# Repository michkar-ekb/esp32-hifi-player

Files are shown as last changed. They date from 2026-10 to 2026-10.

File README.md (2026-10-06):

# S3 Hi-Fi

**English** · [Русский](README.ru.md)

A network Hi-Fi player for your own music library (FLAC, WAV, MP3, DSD) and internet radio. The music lives on a home server;
the player, built on an ESP32-S3, receives a ready-to-play stream over Wi-Fi and feeds it
to an ES9038Q2M DAC. You control it from your phone, in the browser.

> **Status:** in daily use at home. Server 0.5, player firmware 0.6, case and wiring are done.
> No display on purpose: everything is on the phone, cover art included. Next: more connections
> for listening over mobile internet (in a car), and a Windows installer.

<p>
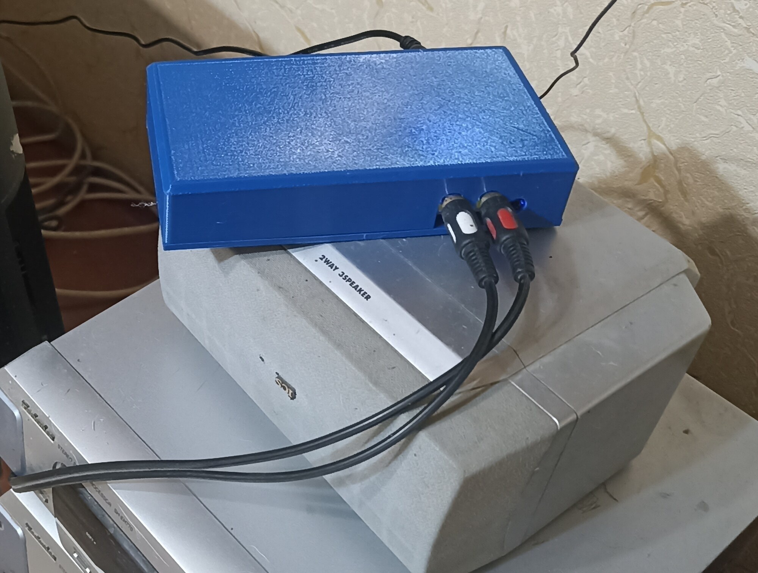
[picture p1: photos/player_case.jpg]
Player in its case on the stereo
  
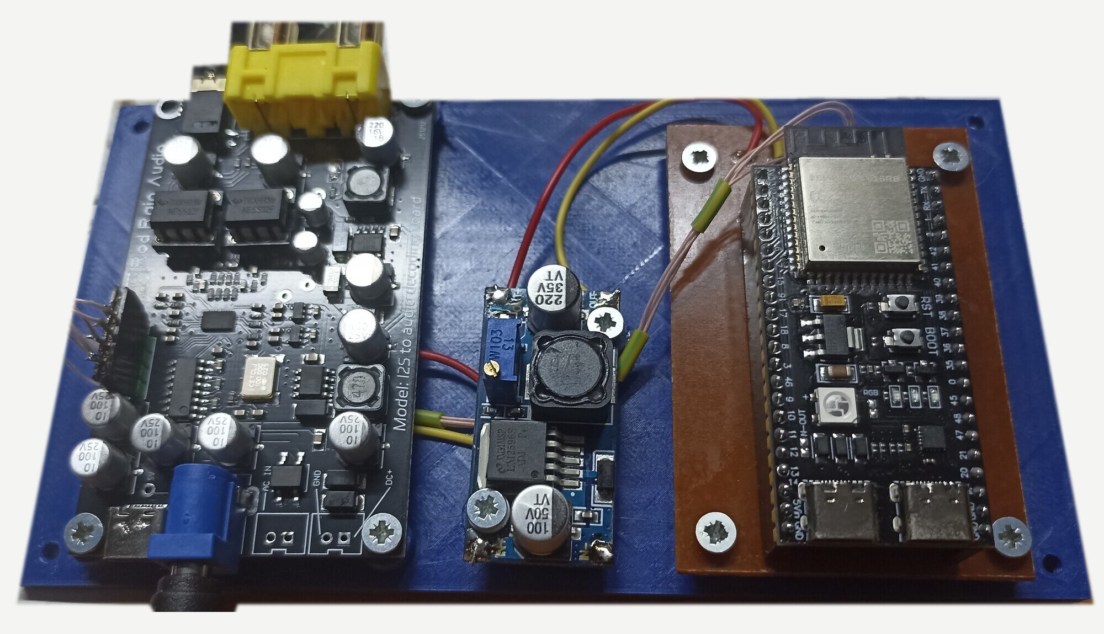
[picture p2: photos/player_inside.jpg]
Inside: DAC, DC-DC module and the ESP32-S3 terminal board
  
</p>

The bench build: in the case on the stereo, and inside.

Block diagram

## Quick start

1. **Server** on a Linux PC that holds the music:
   `curl -fsSL https://raw.githubusercontent.com/michkar-ekb/esp32-hifi-player/main/install.sh | sudo sh -s -- /path/to/music`
   (Windows: [`s3hifi-windows-amd64.exe`](https://github.com/michkar-ekb/esp32-hifi-player/releases/latest), see [server](server)).
2. **Player**: flash `s3hifi-player-esp32s3-n16r8.bin` from [Releases](https://github.com/michkar-ekb/esp32-hifi-player/releases/latest),
   connect a phone to the "S3 Hi-Fi Setup" Wi-Fi and pick your network. The player finds the server by itself.
3. **Remote**: open `http://<server>:8097` on the phone.

## How it works

- **Streaming server** (a home PC or a mini PC, Windows or Linux) stores the music, decodes
  FLAC / WAV / MP3 / DSD and MP3 radio to PCM, keeps the play queue and the radio list,
  and serves the web remote.
- **ESP32-S3** decodes nothing: it receives the PCM stream over TCP, keeps a ~10 second
  buffer in PSRAM and plays it out over I2S at a steady rate. The player sets the pace,
  so the server clock and the player clock never drift apart.
- **ES9038Q2M DAC** has its own oscillator (no MCLK needed) and drives a ~2 V line output
  into an amplifier or powered speakers.

Quality ceiling is 24-bit / 96 kHz: the stream is 4.6 Mbit/s, well within what Wi-Fi delivers.

## Parts

| Block | Part | Notes |
|---|---|---|
| Player | ESP32-S3 DevKitC-1, **N16R8** | PSRAM is required for the buffer |
| DAC | ES9038Q2M board (Rod Rain Audio) | I2S input: GND, BCLK, FSCLK, DATA; RCA output |
| Power | 12 V / 2 A adapter + DC-DC step-down module 12 → 5 V | 12 V goes to the DAC, 5 V to the ESP32-S3 |
| Terminal board | ESP32-S3 terminal board (in this repository) | sockets for the devkit + 6 pads for wires |

## Wiring

Wiring diagram

| ESP32-S3 | Terminal board pad | DAC |
|---|---|---|
| 5V | 5V | — (from the DC-DC module) |
| GND | GND | — (from the DC-DC module) |
| GPIO42 | DATA | DATA |
| GPIO2 | LRCK | FSCLK |
| GPIO1 | BCLK | BCLK |
| GND | GND_A | GND |

Power is split as a **star right at the DAC input jack**: one pair of wires goes to the DAC,
the other to the DC-DC module. The ESP32 current never flows through the DAC's traces.

## ESP32-S3 terminal board

The devkit plugs into sockets, and every signal the player needs comes out to large pads
for soldering wires. Single-sided, 48 × 69.65 mm, all traces on the bottom layer, made for toner transfer
or a marker on a 3D printer.

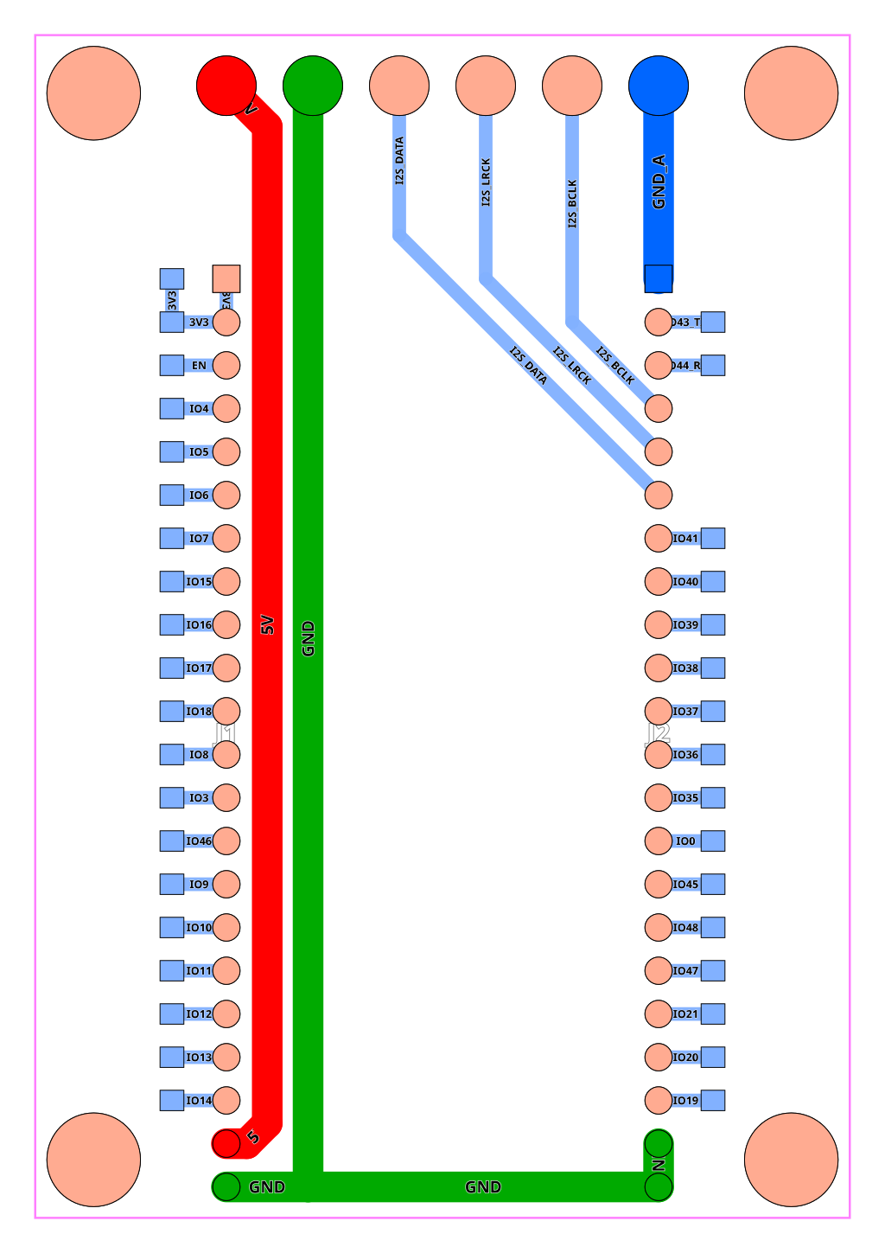
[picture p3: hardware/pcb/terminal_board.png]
Terminal board layout


- `hardware/pcb/terminal_board_gerber.zip` — Gerber files to order or etch the board
- `hardware/pcb/terminal_board_bottom_marker.stl` — bottom layer for marker plotting (mirrored, 0.2 mm)

## Software

- [`server/`](server) — streaming server in Go with the built-in web remote: folders, queue, radio.
  One binary for **Windows and Linux**.
- [`firmware/`](firmware) — player firmware for the ESP32-S3 (Arduino core 2.0.17).

The ES9038Q2M board needs **32-bit I2S samples**; with 16-bit slots it plays noise.
DSD is converted to PCM 24 bit / 88.2 kHz on the server: the board's I2S header cannot carry native DSD.

## Case

3D-printed base plate and lid, `hardware/case/`: the DAC, the DC-DC module and the terminal board
on standoffs; RCA and the headphone jack at the front, 12 V and both USB-C at the rear.
Rounded 3 mm edges, printed without supports. Four M3 × 12 screws hold the lid from below.
This is just one way to house it: any case that fits your modules will do.

## License

Code: MIT. Schematic and board: CC BY-SA 4.0 — build it, change it, just credit the author.

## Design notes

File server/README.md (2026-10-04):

# Streaming server

A single program written in Go. It keeps the music library and the play queue, decodes
everything to PCM and streams it to the player. The web remote for the phone is built in.

- **Formats:** FLAC, WAV (16/24 bit), MP3, DSD (DSF / DFF, DSD64–DSD256) and MP3 internet radio
  are decoded by the server itself.
- **With ffmpeg installed** (optional; next to the server or in PATH) it also plays M4A / ALAC, AAC,
  OGG, Opus, APE, WavPack, AIFF and WMA, and "DTS-WAV" discs: a WAV that actually holds a DTS 5.1
  stream. The server spots DTS / AC-3 inside a WAV and never plays it as PCM (that is loud noise);
  ffmpeg decodes it and downmixes to stereo.
- **DSD** is converted to PCM 24 bit / 88.2 kHz with a linear-phase FIR (Kaiser window),
  because the DAC board's I2S header cannot carry native DSD.
- **Bit-perfect** for PCM files: the stream is identical to what ffmpeg decodes;
  seeking is sample-accurate and track changes are gapless.
- **SACD disc images** (`.iso`): the stereo area is shown as songs with titles from the disc and played
  through the same DSD filter. DST-compressed discs are not supported yet.
- **CUE sheets:** an album ripped as one big file (APE / FLAC / WAV) plus a `.cue` is shown as separate
  songs; each plays from its start to the next one, gapless. Windows-1251 cue files (common in Russian
  rips) are read correctly, and a cue that says `album.wav` next to `album.ape` still finds the file.
- **Fast seeking without seek tables:** FLAC and WavPack files are bisected for the right frame/block,
  so a song in the middle of an 80-minute album file starts in a second instead of reading the whole file.
- **Above 96 kHz the server resamples** (SoX resampler via ffmpeg): 176.4/352.8 kHz → 88.2 kHz,
  192/384 kHz → 96 kHz, still 24 bit. 24/192 would be 9.2 Mbit/s — more than the player gets over Wi-Fi.
- **Network shares are fine:** files are read 32 MB ahead in the background, so a share that
  stalls for a few seconds is not heard.
- **Covers from the internet:** when a folder has no cover image, the server looks the album up in the
  iTunes Search API by the folder name ("Artist - Album (year) [...]"), falling back to the song; for
  internet radio it shows the cover of the song that is playing. A picture is taken only if the artist
  matches, and each one is fetched once and kept in the data folder. `-online-covers=false` turns it off.
- **Queue:** tapping a folder or an album replaces the queue with it and plays it from the start;
  tapping a single song or a radio station plays it right away without touching the queue
  ("next" then goes on with the queue); only the ＋ button adds to the queue.
- **Over the internet:** the server can run on a VPS and the player can reach it through a phone's
  mobile hotspot (set the server address on the player's setup page). Tested: CD-quality FLAC plays
  without dropouts over 4G; DSD and 24/96 need more than the player gets there (~2 Mbit/s at 40–70 ms).
  The web remote has no password, so do not leave it open to the whole internet.
- **One binary, no dependencies.** Builds for Windows and Linux (x86-64 and ARM).
  So far it has been run on Linux only.

## Install

### Linux — one command

```bash
curl -fsSL https://raw.githubusercontent.com/michkar-ekb/esp32-hifi-player/main/install.sh | sudo sh -s -- /path/to/music
```

The script downloads the latest release for your CPU (x86-64, ARM64 such as Raspberry Pi 4/5,
ARMv7 such as Orange Pi / older Raspberry Pi), installs it to `/opt/s3hifi`, creates the `s3hifi`
service that starts with the system and runs as your user, and opens port **8097** (TCP for the remote
and the stream, UDP for player discovery) in firewalld or ufw. Without a folder argument it uses
`~/Music`. Run the same command again to update.

Optional: `sudo dnf install ffmpeg` / `sudo apt install ffmpeg` — for DTS, APE, M4A, OGG,
WavPack and files above 96 kHz.

Then open `http://<this-computer>:8097` on the phone.

### Linux — by hand

1. Download `s3hifi-linux-amd64` (or `-arm64`, `-armv7`) from
   [Releases](https://github.com/michkar-ekb/esp32-hifi-player/releases/latest), save it as
   `/opt/s3hifi/s3hifi`, `chmod +x` it.
2. Try it: `/opt/s3hifi/s3hifi -music ~/Music -data /opt/s3hifi/data`.
3. Start with the system — `/etc/systemd/system/s3hifi.service`:

   ```ini
   [Unit]
   Description=S3 Hi-Fi streaming server
   Wants=network-online.target
   After=network-online.target remote-fs.target

   [Service]
   User=your-user
   ExecStart=/opt/s3hifi/s3hifi -music /home/your-user/Music -data /opt/s3hifi/data -listen :8097
   Restart=always
   RestartSec=5

   [Install]
   WantedBy=multi-user.target
   ```

   `sudo systemctl enable --now s3hifi`
4. Open port 8097 TCP and UDP: `sudo firewall-cmd --permanent --add-port=8097/tcp --add-port=8097/udp && sudo firewall-cmd --reload`
   (Ubuntu: `sudo ufw allow 8097`).

If the music folder is a network share that is not mounted yet, the server still starts:
radio works and the folders appear once the share is up.

### Windows

No installer yet. Download `s3hifi-windows-amd64.exe` from
[Releases](https://github.com/michkar-ekb/esp32-hifi-player/releases/latest), put it in a folder and run:

```
s3hifi-windows-amd64.exe -music "D:\Music"
```

Allow it in the Windows firewall when asked (private networks). For DTS, APE and other extra formats put
`ffmpeg.exe` and `ffprobe.exe` next to it (any LGPL build). Windows has been tested less than Linux.

### Build from source

```bash
cd server
go build -o s3hifi .
```

### Options

| Flag | Default | |
|---|---|---|
| `-music` | `~/Music` | music folder |
| `-data` | `~/.s3hifi` | queue, volume, radio list, cover cache, pictures from the internet |
| `-listen` | `:8097` | address of the web remote and the player stream |
| `-version` | | print the version |
| `-online-covers` | `true` | look up missing album covers and radio song pictures on the internet (iTunes) |

Folders are browsed as they are on disk; a `cover.jpg` / `folder.jpg` (or any image) in an album
folder is used as the cover.

## Player protocol

The player (ESP32-S3) talks plain HTTP/1.0:

- `GET /esp/poll?epoch=E&played=N&buf=ms&rssi=dBm` — about 4 times a second. The answer is
  `epoch state volume`, for example `5 play 70`. `played` is the number of frames the player
  has output in this epoch; the server uses it to show what is really heard.
- `GET /esp/stream?epoch=E&lane=L&lanes=N` — the PCM stream of the epoch, spread over **N parallel
  connections** (the player uses 4). Chunk *n* goes to lane *n mod N*, the player reads the lanes in the
  same order. Chunk: `"S3P2"` · rate `u32` · bits `u8` (16/24) · channels `u8` · flags `u8` (1 = new track) ·
  `0` · length `u32` · sequence `u32` · PCM data (little-endian, ≤ 4 KB).

  Why lanes: the Arduino ESP32 core has a fixed 5.7 KB TCP window, so one connection tops out at
  ~5 Mbit/s on a Wi-Fi link with 8 ms round trip. DSD converted to 88.2 kHz / 24 bit needs 4.2 Mbit/s,
  24/96 FLAC 4.6. Four lanes give several times that.
- If a lane breaks, the player polls with `&resync=1` and the server restarts the epoch from the
  position that has actually been heard.

Every change of what is heard (new track, seek, stop) starts a new **epoch**: the player drops
its buffer and reconnects. Pause and volume do not change the epoch and act on the player at once.
The player sets the pace: it reads from the network only as fast as it plays, so the clocks never drift.

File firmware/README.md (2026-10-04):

# ESP32-S3 firmware

`player_fw/` — the player, version 0.6. It decodes nothing: it receives PCM from the
[server](../server), keeps up to ~40 s of CD audio (~12 s of 24/96) in PSRAM, stored as it came (16 or 24 bit) and plays it out over I2S.

- I2S pins: **BCLK = GPIO1, LRCK = GPIO2, DATA = GPIO42**, no MCLK.
- The ES9038Q2M board needs **32-bit I2S samples**: with 16-bit slots it only produces noise.
  16- and 24-bit audio is placed in the upper bits of 32-bit samples.
- The stream comes over **4 TCP connections**: the core's 5.7 KB TCP window limits one connection
  to ~5 Mbit/s, not enough for DSD or 24/96 on a typical home Wi-Fi.
- The network is read through plain lwIP sockets with 8 KB reads: `WiFiClient` copies everything
  through a 1.4 KB buffer, and at 4+ Mbit/s that overhead made the player fall behind.
  Receive rate is reported to the server and shown in the remote (5–8 Mbit/s on a good link).
- Three tasks: network stream and server poll on core 0, I2S output on core 1 with high priority.
  Pause and volume act immediately; a new track or a seek drops the buffer, and playback starts
  again once 2 s of sound have arrived (so a slow link does not stutter right after a skip).

## Flash a ready build

Download `s3hifi-player-esp32s3-n16r8.bin` from
[Releases](https://github.com/michkar-ekb/esp32-hifi-player/releases/latest): bootloader, partitions
and firmware in one image, written at address 0. Connect the devkit by USB and run:

```
esptool.py --chip esp32s3 write_flash 0x0 s3hifi-player-esp32s3-n16r8.bin
```

(`pip install esptool`; on Windows the Arduino IDE already ships `esptool.exe`.) The image is built
for ESP32-S3 N16R8 (16 MB flash, 8 MB octal PSRAM).

## First start

No Wi-Fi settings are compiled in. On first start (or when the saved network is gone for a minute)
the player opens the access point **"S3 Hi-Fi Setup"**; connect a phone to it and the setup page opens
by itself (or go to `192.168.4.1`). Pick your network, type the password, save. The server is found
automatically: the player broadcasts `S3HIFI?` on UDP port 8097 and the server answers. A server
address can still be typed in on the setup page (`host` or `host:port`), for example a server on a VPS
on the internet. Holding **BOOT** for 5 seconds erases the settings.

The same setup page also opens at the player's own address in the home network (the remote links to
it as "настройки плеера"): it shows the network, signal and server, and lets you change them. A blank
password keeps the saved one.

## Build

Arduino core for ESP32 **2.0.17**, board settings:

```
arduino-cli compile --fqbn esp32:esp32:esp32s3:PSRAM=opi,FlashSize=16M player_fw
```

Nothing to edit before building: Wi-Fi is set up from a phone (see above).

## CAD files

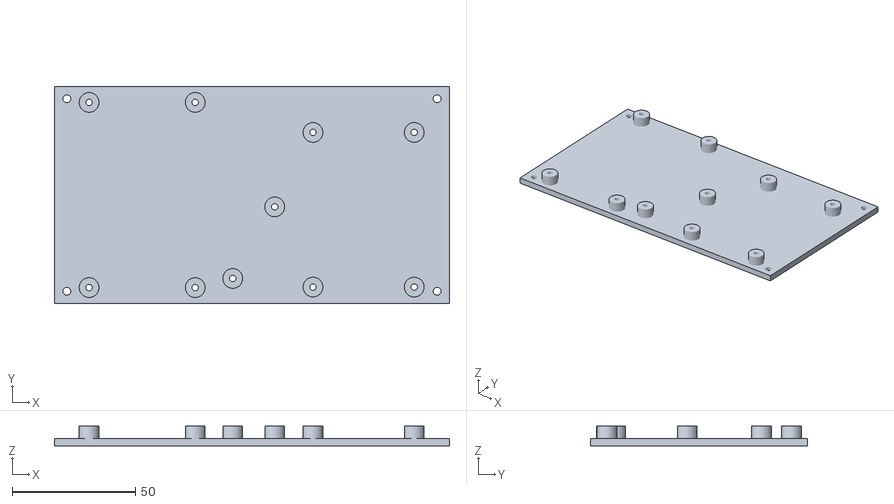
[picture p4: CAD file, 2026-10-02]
hardware/case/platform.stl
160.0 x 88.0 x 8.00

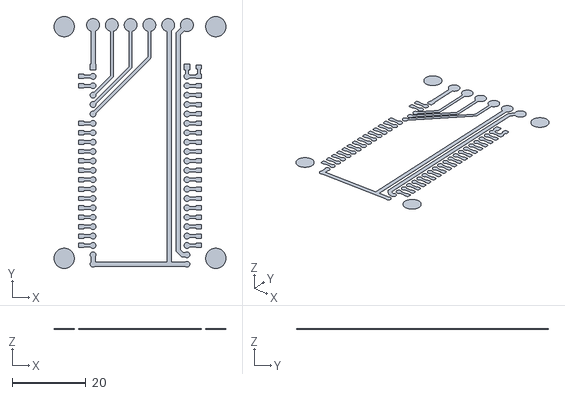
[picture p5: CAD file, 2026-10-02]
hardware/pcb/terminal_board_bottom_marker.stl
46.5 x 68.2 x 0.2

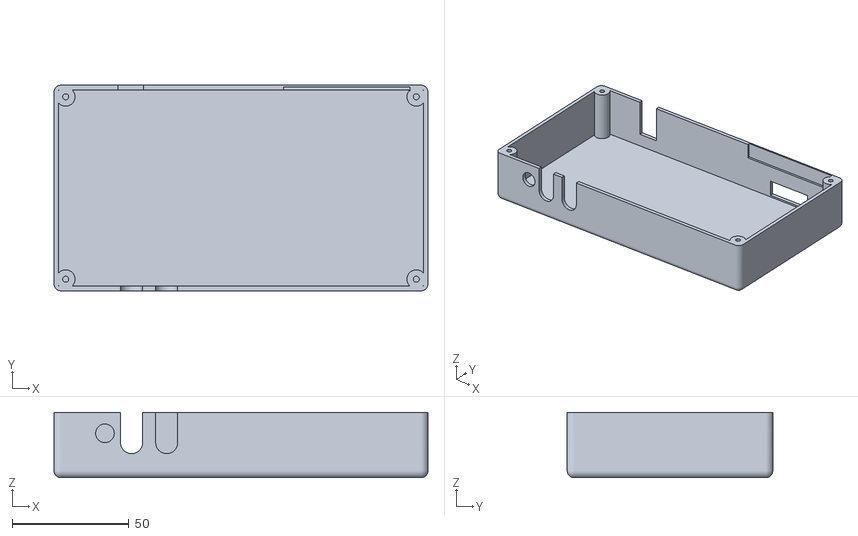
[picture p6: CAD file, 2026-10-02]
hardware/case/lid.stl
160.0 x 88.0 x 28.0

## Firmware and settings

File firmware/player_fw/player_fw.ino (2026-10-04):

// S3 Hi-Fi player firmware v0.6 — thin client of the S3 Hi-Fi server.
// The server decodes everything to PCM; the player keeps a ~10 s buffer in PSRAM and
// clocks it out over I2S as 32-bit samples (what the ES9038Q2M board expects).
//
//   stream task (core 0): GET /esp/stream?epoch=E&lane=L over 4 connections -> PCM chunks -> ring buffer
//   poll task   (core 0): GET /esp/poll ... 4 times a second -> epoch, play/pause/stop, volume
//   i2s task    (core 1): ring buffer -> volume -> I2S; pause and volume act immediately
//
// A new epoch (new track, seek, stop) means: drop the buffer and reconnect.
// Build: esp32:esp32:esp32s3:PSRAM=opi,FlashSize=16M (core 2.0.17)
#include <WiFi.h>
#include <driver/i2s.h>
#include <math.h>
#include <lwip/sockets.h>
#include <Preferences.h>
#include <WebServer.h>
#include <DNSServer.h>
#include <WiFiUdp.h>
#include "lane.h"

// ---------- settings ----------
// Wi-Fi and the server are set up from a phone: with no saved network (or if it is lost for a minute)
// the player opens the access point "S3 Hi-Fi Setup" with a setup page. The server is found by itself:
// the player broadcasts "S3HIFI?" on UDP 8097 and the server answers. Holding BOOT for 5 s erases the settings.
const char *AP_NAME = "S3 Hi-Fi Setup";
const uint16_t DISCOVERY_PORT = 8097;
String cfgSsid, cfgPass, cfgServer;     // saved in NVS; cfgServer empty = find automatically
char serverIp[40] = "";
volatile uint16_t serverPort = 8097;
volatile bool serverKnown = false;

#define I2S_BCLK 1
#define I2S_LRCK 2
#define I2S_DOUT 42

// ---------- ring buffer in PSRAM: PCM bytes exactly as they came (stereo, 16 or 24 bit) ----------
// Kept compact: 16-bit audio takes 4 bytes per frame, 24-bit 6. It is widened to the 32-bit samples
// the DAC wants only on the way out. With ~7 MB that is ~40 s of CD audio, ~12 s of 24/96.
uint8_t *ring;
uint32_t ringBytes;                     // multiple of 12, so 4- and 6-byte frames tile it
volatile uint64_t wr = 0, rd = 0;       // total bytes written / read since boot

struct FmtMark { uint64_t pos; uint32_t rate; uint8_t bits; };   // from byte `pos` on, data is rate/bits
const int MARKS = 32;
FmtMark marks[MARKS];
volatile int markHead = 0, markTail = 0;
uint32_t writeRate = 0;                 // format of the data the stream task writes
uint8_t writeBits = 0;

void ringWrite(const uint8_t *src, uint32_t n) {
  uint32_t at = (uint32_t)(wr % ringBytes), first = min(n, ringBytes - at);
  memcpy(ring + at, src, first);
  if (n > first) memcpy(ring, src + first, n - first);
}

void ringRead(uint8_t *dst, uint32_t n) {
  uint32_t at = (uint32_t)(rd % ringBytes), first = min(n, ringBytes - at);
  memcpy(dst, ring + at, first);
  if (n > first) memcpy(dst + first, ring, n - first);
}

// ---------- shared state ----------
volatile uint32_t serverEpoch = 0;      // latest epoch from poll
volatile uint32_t streamEpoch = 0;      // epoch the buffer belongs to
volatile bool flushReq = false;
volatile char playState = 's';          // 'p' play, 'z' pause, 's' stop
volatile int volumePct = 70;
volatile uint64_t played = 0;           // frames played since the last flush
volatile uint32_t outRate = 44100;       // format being played now
volatile uint8_t outBits = 16;
volatile bool srcIdle = true;           // stream task has no connection (nothing more coming)

// ---------- I2S ----------
void i2sInit() {
  i2s_config_t cfg = {};
  cfg.mode = (i2s_mode_t)(I2S_MODE_MASTER | I2S_MODE_TX);
  cfg.sample_rate = 44100;
  cfg.bits_per_sample = I2S_BITS_PER_SAMPLE_32BIT;
  cfg.channel_format = I2S_CHANNEL_FMT_RIGHT_LEFT;
  cfg.communication_format = I2S_COMM_FORMAT_STAND_I2S;
  cfg.intr_alloc_flags = ESP_INTR_FLAG_LEVEL1;
  cfg.dma_buf_count = 8;
  cfg.dma_buf_len = 256;
  cfg.tx_desc_auto_clear = true;
  i2s_driver_install(I2S_NUM_0, &cfg, 0, nullptr);
  i2s_pin_config_t pins = {};
  pins.mck_io_num = I2S_PIN_NO_CHANGE;
  pins.bck_io_num = I2S_BCLK;
  pins.ws_io_num = I2S_LRCK;
  pins.data_out_num = I2S_DOUT;
  pins.data_in_num = I2S_PIN_NO_CHANGE;
  i2s_set_pin(I2S_NUM_0, &pins);
}

float volumeGain(int v) {               // 100 = 0 dB, 0.4 dB per step, 0 = mute
  if (v <= 0) return 0;
  return powf(10.0f, -(100 - v) * 0.4f / 20.0f);
}

const uint32_t PREBUFFER_MS = 2000;

void i2sTask(void *) {
  const int N = 256;
  static int32_t out[N * 2];
  static uint8_t raw[N * 6];
  bool prebuffer = true;
  for (;;) {
    if (flushReq) {
      rd = wr;
      markTail = markHead;
      played = 0;
      prebuffer = true;
      flushReq = false;
    }
    while (markTail != markHead && marks[markTail].pos <= rd) {   // format changes at this point
      uint32_t r = marks[markTail].rate;
      outBits = marks[markTail].bits;
      markTail = (markTail + 1) % MARKS;
      if (r != outRate) {
        i2s_set_clk(I2S_NUM_0, r, I2S_BITS_PER_SAMPLE_32BIT, I2S_CHANNEL_STEREO);
        outRate = r;
      }
    }
    uint32_t fsz = outBits / 8 * 2;
    uint64_t avail = wr - rd;
    // after a new track, seek or underrun: gather PREBUFFER_MS of sound before starting (short tracks: what there is)
    if (prebuffer && (avail >= (uint64_t)outRate * fsz * PREBUFFER_MS / 1000 || (srcIdle && avail > 0))) prebuffer = false;
    if (playState == 'p' && !prebuffer && avail >= fsz) {
      uint64_t lim = avail;
      if (markTail != markHead && marks[markTail].pos - rd < lim) lim = marks[markTail].pos - rd;
      uint32_t n = lim / fsz < (uint64_t)N ? (uint32_t)(lim / fsz) : N;
      if (n == 0) { vTaskDelay(1); continue; }
      ringRead(raw, n * fsz);
      float g = volumeGain(volumePct);
      const uint8_t *p = raw;
      for (uint32_t i = 0; i < n * 2; i++) {          // widen to the 32-bit samples of the I2S bus
        int32_t v;
        if (fsz == 4) { v = (int32_t)((uint32_t)(p[0] | p[1] << 8) << 16); p += 2; }
        else { v = (int32_t)((uint32_t)p[0] << 8 | (uint32_t)p[1] << 16 | (uint32_t)p[2] << 24); p += 3; }
        out[i] = (int32_t)(v * g);
      }
      size_t w;
      i2s_write(I2S_NUM_0, out, n * 8, &w, portMAX_DELAY);
      rd += n * fsz;
      played += n;
      if (wr == rd && !srcIdle) prebuffer = true;  // underrun: refill a little before continuing
    } else {
      memset(out, 0, sizeof(out));                // keep the clock running: no pops
      size_t w;
      i2s_write(I2S_NUM_0, out, sizeof(out), &w, portMAX_DELAY);
    }
  }
}

// ---------- network helpers ----------
// ---------- network: plain lwIP sockets, big reads, blocking with a short timeout ----------
// (WiFiClient copies everything through a 1.4 KB buffer; at 4+ Mbit/s on four connections
//  that overhead made the player fall behind.)
volatile uint32_t rxBytes = 0;          // total payload bytes received, for the kbit/s report

void laneClose(Lane &L) {
  if (L.fd >= 0) close(L.fd);
  L.fd = -1;
  L.pos = L.len = 0;
}

// Reads exactly n bytes. False on disconnect or when the epoch changes.
bool laneRead(Lane &L, uint8_t *dst, size_t n, uint32_t epoch) {
  while (n) {
    if (L.pos < L.len) {
      size_t k = L.len - L.pos < n ? L.len - L.pos : n;
      memcpy(dst, L.buf + L.pos, k);
      L.pos += k; dst += k; n -= k;
      continue;
    }
    if (serverEpoch != epoch) return false;
    // large request and empty buffer: receive straight into the destination
    uint8_t *to = n >= 2048 ? dst : L.buf;
    size_t cap = n >= 2048 ? n : sizeof(L.buf);
    int r = recv(L.fd, to, cap, 0);
    if (r > 0) {
      rxBytes += r;
      if (to == dst) { dst += r; n -= r; } else { L.pos = 0; L.len = r; }
    } else if (r < 0 && (errno == EAGAIN || errno == EWOULDBLOCK)) {
      continue;                          // timeout: re-check the epoch
    } else {
      return false;                      // closed or error
    }
  }
  return true;
}

bool laneOpen(Lane &L, uint32_t epoch, int lane, int lanes) {
  laneClose(L);
  L.fd = socket(AF_INET, SOCK_STREAM, IPPROTO_TCP);
  if (L.fd < 0) return false;
  int one = 1;
  setsockopt(L.fd, IPPROTO_TCP, TCP_NODELAY, &one, sizeof(one));
  struct timeval tv = { 0, 200000 };     // 200 ms: wake up to notice an epoch change
  setsockopt(L.fd, SOL_SOCKET, SO_RCVTIMEO, &tv, sizeof(tv));
  struct sockaddr_in a = {};
  a.sin_family = AF_INET;
  a.sin_port = htons(serverPort);
  a.sin_addr.s_addr = inet_addr(serverIp);
  if (connect(L.fd, (struct sockaddr *)&a, sizeof(a)) != 0) { laneClose(L); return false; }
  char req[160];
  int k = snprintf(req, sizeof(req), "GET /esp/stream?epoch=%u&lane=%d&lanes=%d HTTP/1.0\r\nHost: %s\r\n\r\n",
                   epoch, lane, lanes, serverIp);
  if (send(L.fd, req, k, 0) != k) { laneClose(L); return false; }
  uint32_t last4 = 0;                    // skip the HTTP header up to "\r\n\r\n"
  uint8_t b;
  while (last4 != 0x0D0A0D0A) {
    if (!laneRead(L, &b, 1, epoch)) { laneClose(L); return false; }
    last4 = (last4 << 8) | b;
  }
  return true;
}

void pushFormat(uint32_t r, uint8_t bits) {
  if (r == writeRate && bits == writeBits) return;
  marks[markHead] = { wr, r, bits };
  markHead = (markHead + 1) % MARKS;
  writeRate = r;
  writeBits = bits;
}

// The ESP32 TCP window is fixed at 5.7 KB (Arduino core), which caps one connection at ~5 Mbit/s
// on Wi-Fi with 8 ms RTT. So the stream comes over LANES connections: chunk n arrives on lane n % LANES,
// we read them in that order, and while we read one lane the others keep filling their windows.
const int LANES = 4;
volatile bool resyncReq = false;       // a lane broke: ask the server to restart from what was heard

bool readChunkInto(Lane &c, uint32_t epoch, uint32_t seq) {
  uint8_t h[20];
  if (!laneRead(c, h, 20, epoch)) return false;
  if (memcmp(h, "S3P2", 4) != 0) { Serial.println("stream: bad chunk"); return false; }
  uint32_t rate = h[4] | h[5] << 8 | h[6] << 16 | (uint32_t)h[7] << 24;
  uint8_t bits = h[8], ch = h[9];
  uint32_t len = h[12] | h[13] << 8 | h[14] << 16 | (uint32_t)h[15] << 24;
  uint32_t sq = h[16] | h[17] << 8 | h[18] << 16 | (uint32_t)h[19] << 24;
  uint32_t fsz = bits / 8 * ch;
  if (sq != seq) { Serial.printf("stream: seq %u, want %u\n", sq, seq); return false; }
  if ((bits != 16 && bits != 24) || ch < 1 || ch > 2 || len % fsz || len > 8192) { Serial.println("stream: bad format"); return false; }
  static uint8_t buf[8192], st[16384];
  if (!laneRead(c, buf, len, epoch)) return false;
  const uint8_t *data = buf;
  uint32_t n = len;
  if (ch == 1) {                                   // the ring is always stereo: duplicate mono
    uint32_t bs = bits / 8;
    for (uint32_t i = 0, o = 0; i < len; i += bs, o += 2 * bs) {
      memcpy(st + o, buf + i, bs);
      memcpy(st + o + bs, buf + i, bs);
    }
    data = st;
    n = len * 2;
  }
  while (ringBytes - (wr - rd) < n) {              // ring full: wait for the I2S side
    if (serverEpoch != epoch) return false;
    vTaskDelay(pdMS_TO_TICKS(5));
  }
  pushFormat(rate, bits);
  ringWrite(data, n);
  wr += n;
  return true;
}

// All lanes of `epoch`. Returns when the epoch changes or a lane drops.
void streamOnce(uint32_t epoch) {
  static Lane c[LANES];
  bool ok = true;
  for (int l = 0; l < LANES && ok; l++) ok = laneOpen(c[l], epoch, l, LANES);
  if (ok) {
    srcIdle = false;
    for (uint32_t seq = 0; readChunkInto(c[seq % LANES], epoch, seq); seq++) {}
  }
  for (int l = 0; l < LANES; l++) laneClose(c[l]);
  srcIdle = true;
  if (serverEpoch == epoch) {      // not an epoch change: the link broke, restart from what was heard
    Serial.println("stream: lane lost, resync");
    resyncReq = true;
    for (int i = 0; i < 40 && serverEpoch == epoch; i++) vTaskDelay(pdMS_TO_TICKS(50));
  }
}

void streamTask(void *) {
  for (;;) {
    if (WiFi.status() != WL_CONNECTED || !serverKnown) { vTaskDelay(pdMS_TO_TICKS(500)); continue; }
    uint32_t e = serverEpoch;
    if (e != streamEpoch) {          // new epoch: drop everything that was buffered
      flushReq = true;
      while (flushReq) vTaskDelay(1);
      writeRate = 0;
      writeBits = 0;
      streamEpoch = e;
    }
    if (playState == 's') { vTaskDelay(pdMS_TO_TICKS(100)); continue; }
    streamOnce(e);
  }
}

void pollTask(void *) {
  for (;;) {
    vTaskDelay(pdMS_TO_TICKS(250));
    static int fails = 0;
    if (WiFi.status() != WL_CONNECTED || !serverKnown) continue;
    WiFiClient c;
    if (!c.connect(serverIp, serverPort, 1000)) {
      if (++fails >= 12 && cfgServer.isEmpty()) serverKnown = false;   // server moved? look for it again
      continue;
    }
    fails = 0;
    uint32_t bufMs = outRate ? (uint32_t)((wr - rd) * 1000 / ((uint64_t)outRate * (outBits / 8 * 2))) : 0;
    bool rs = resyncReq;
    static uint32_t lastBytes = 0, lastMs = 0;
    uint32_t now = millis(), bytes = rxBytes;
    uint32_t kbps = lastMs && now > lastMs ? (uint32_t)((uint64_t)(bytes - lastBytes) * 8 / (now - lastMs)) : 0;
    lastBytes = bytes; lastMs = now;
    c.printf("GET /esp/poll?epoch=%u&played=%llu&buf=%u&rssi=%d&kbps=%u%s HTTP/1.0\r\nHost: %s\r\n\r\n",
             streamEpoch, (unsigned long long)played, bufMs, WiFi.RSSI(), kbps, rs ? "&resync=1" : "", serverIp);
    if (rs) resyncReq = false;
    String resp;
    uint32_t t0 = millis();
    while (millis() - t0 < 1000 && (c.connected() || c.available())) {
      while (c.available()) resp += (char)c.read();
      vTaskDelay(1);
    }
    c.stop();
    int body = resp.indexOf("\r\n\r\n");
    if (body < 0) continue;
    unsigned e = 0, v = 0;
    char st[8] = {0};
    if (sscanf(resp.c_str() + body + 4, "%u %7s %u", &e, st, &v) == 3) {
      volumePct = v;
      playState = !strcmp(st, "play") ? 'p' : !strcmp(st, "pause") ? 'z' : 's';
      serverEpoch = e;
    }
  }
}

// ---------- finding the server ----------
void discoveryTask(void *) {
  WiFiUDP udp;
  for (;;) {
    vTaskDelay(pdMS_TO_TICKS(1000));
    if (serverKnown || WiFi.status() != WL_CONNECTED) continue;
    if (!cfgServer.isEmpty()) {                       // typed in on the setup page
      IPAddress ip;
      String host = cfgServer;
      int colon = host.indexOf(':');
      if (colon > 0) { serverPort = host.substring(colon + 1).toInt(); host = host.substring(0, colon); }
      if (ip.fromString(host) || WiFi.hostByName(host.c_str(), ip)) {
        strlcpy(serverIp, ip.toString().c_str(), sizeof(serverIp));
        serverKnown = true;
        Serial.printf("server (set by hand): %s:%u\n", serverIp, serverPort);
      }
      continue;
    }
    udp.begin(0);
    udp.beginPacket(WiFi.broadcastIP(), DISCOVERY_PORT);
    udp.print("S3HIFI?");
    udp.endPacket();
    uint32_t t0 = millis();
    while (millis() - t0 < 800) {
      if (udp.parsePacket() > 0) {
        char b[32] = {0};
        udp.read(b, sizeof(b) - 1);
        if (!strncmp(b, "S3HIFI ", 7)) {
          serverPort = atoi(b + 7);
          strlcpy(serverIp, udp.remoteIP().toString().c_str(), sizeof(serverIp));
          serverKnown = true;
          Serial.printf("server found: %s:%u\n", serverIp, serverPort);
          break;
        }
      }
      vTaskDelay(pdMS_TO_TICKS(20));
    }
    udp.stop();
  }
}

// ---------- setup access point and page ----------
String htmlEsc(const String &s) {
  String o;
  for (char ch : s) {
    if (ch == '<') o += "&lt;"; else if (ch == '>') o += "&gt;"; else if (ch == '"') o += "&quot;"; else if (ch == '&') o += "&amp;"; else o += ch;
  }
  return o;
}

WebServer web(80);
DNSServer dns;
bool portalOn = false;
String netOptions;                                    // <option>s from the last scan

// Scanning makes the access point hop channels and drops the phone that is on the setup page,
// so we scan before the point goes up (and again only when asked).
void scanNetworks() {
  int n = WiFi.scanNetworks();
  netOptions = "";
  for (int i = 0; i < n; i++) {
    String ss = WiFi.SSID(i);
    if (ss.isEmpty() || netOptions.indexOf("\"" + htmlEsc(ss) + "\"") >= 0) continue;
    netOptions += "<option value=\"" + htmlEsc(ss) + "\"" + (ss == cfgSsid ? " selected" : "") + ">" + htmlEsc(ss) +
                  " (" + WiFi.RSSI(i) + " dBm)</option>";
  }
  WiFi.scanDelete();
}


const char PAGE_HEAD[] PROGMEM = R"(<!doctype html><html lang="ru"><head><meta charset="utf-8">
<meta name="viewport" content="width=device-width,initial-scale=1"><title>S3 Hi-Fi</title><style>
body{margin:0;padding:20px 16px;background:#121214;color:#ecebe8;font:16px/1.4 system-ui,sans-serif}
h1{font-size:20px;margin:0 0 4px}p{color:#8f8d88;margin:0 0 16px}label{display:block;margin:14px 0 6px}
select,input{width:100%;box-sizing:border-box;height:46px;border-radius:10px;border:1px solid #2a2a30;background:#1b1b1f;color:#ecebe8;padding:0 12px;font:inherit}
button{margin-top:20px;width:100%;height:50px;border:0;border-radius:10px;background:#d4a95a;color:#1a1408;font:600 17px system-ui}
small{color:#8f8d88}</style></head><body>)";

void pageRoot() {
  String h = FPSTR(PAGE_HEAD);
  bool home = WiFi.status() == WL_CONNECTED;          // opened at the player's address in the home network
  h += "<h1>S3 Hi-Fi — настройка</h1>";
  if (home) {
    h += "<p>Плеер в сети «" + htmlEsc(cfgSsid) + "», адрес " + WiFi.localIP().toString() + ", сигнал " + WiFi.RSSI() + " dBm.<br>Сервер: " +
         (serverKnown ? String(serverIp) + ":" + serverPort : String("ищу…")) + (cfgServer.isEmpty() ? " (найден сам)" : " (задан вручную)") + "</p>";
  } else {
    h += "<p>Выберите домашнюю сеть Wi-Fi. Сервер плеер найдёт сам.</p>";
  }
  h += "<form method=post action=/save><label for=ssid>Сеть Wi-Fi</label><select id=ssid name=ssid>";
  if (netOptions.isEmpty() && !cfgSsid.isEmpty()) h += "<option value=\"" + htmlEsc(cfgSsid) + "\" selected>" + htmlEsc(cfgSsid) + "</option>";
  h += netOptions;
  h += "<option value=\"\">другая сеть…</option></select>";
  h += "<p style=\"margin:8px 0 0\"><small><a style=\"color:#d4a95a\" href=/rescan>Обновить список</a> — "
       "телефон на пару секунд отключится от точки, потом вернётся</small></p>";
  h += "<label for=other>Имя сети, если её нет в списке</label><input id=other name=other autocomplete=off>";
  h += "<label for=pass>Пароль</label><input id=pass name=pass type=password autocomplete=off" +
       String(cfgPass.isEmpty() ? "" : " placeholder=\"не менять\"") + ">";
  h += "<label for=server>Адрес сервера <small>(можно не заполнять)</small></label><input id=server name=server value=\"" + htmlEsc(cfgServer) + "\" placeholder=\"найти автоматически\">";
  h += "<p style=\"margin:8px 0 0\"><small>Пусто — искать сервер в домашней сети. Для сервера в интернете: адрес или адрес:порт.</small></p>";
  h += "<button>Сохранить и подключиться</button></form>";
  h += "<p style=\"margin-top:24px\"><small>Плеер " + WiFi.macAddress() + ". Чтобы стереть настройки, держите кнопку BOOT 5 секунд.</small></p></body></html>";
  web.send(200, "text/html; charset=utf-8", h);
}

void pageSave() {
  String ss = web.arg("ssid");
  if (ss.isEmpty()) ss = web.arg("other");
  ss.trim();
  if (ss.isEmpty()) { web.sendHeader("Location", "/"); web.send(302); return; }
  Preferences prefs;
  prefs.begin("s3hifi", false);
  prefs.putString("ssid", ss);
  String pw = web.arg("pass");
  if (pw.isEmpty() && ss == cfgSsid) pw = cfgPass;    // left blank: keep the saved password
  prefs.putString("pass", pw);
  String sv = web.arg("server"); sv.trim();
  prefs.putString("server", sv);
  prefs.end();
  String h = FPSTR(PAGE_HEAD);
  h += "<h1>Сохранено</h1><p>Плеер перезагружается и подключается к сети «" + htmlEsc(ss) + "». "
       "Если пароль неверный, через минуту снова появится сеть «S3 Hi-Fi Setup».</p>";
  if (WiFi.status() == WL_CONNECTED)
    h += "<p>Через полминуты страница снова откроется по адресу <a style=\"color:#d4a95a\" href=/>" + WiFi.localIP().toString() + "</a>.</p>";
  h += "</body></html>";
  web.send(200, "text/html; charset=utf-8", h);
  delay(1500);
  ESP.restart();
}

void startPortal() {
  if (portalOn) return;
  WiFi.mode(WIFI_STA);
  scanNetworks();                                     // before the access point: see scanNetworks()
  WiFi.mode(cfgSsid.isEmpty() ? WIFI_AP : WIFI_AP_STA);
  WiFi.softAP(AP_NAME);
  delay(100);
  dns.start(53, "*", WiFi.softAPIP());                // every name -> us: the phone shows the page by itself
  portalOn = true;
  Serial.printf("setup access point \"%s\" at %s\n", AP_NAME, WiFi.softAPIP().toString().c_str());
}
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
void loop() {
  static uint32_t t = 0, lastOk = millis(), lastTry = 0, bootDown = 0, okSince = 0;
  bool up = WiFi.status() == WL_CONNECTED;
  if (portalOn) dns.processNextRequest();
  web.handleClient();
  if (up) {
    lastOk = millis();
    if (!okSince) okSince = millis();
    if (portalOn && !cfgSsid.isEmpty() && millis() - okSince > 3000) stopPortal();   // the saved network works again
  } else {
    okSince = 0;
    serverKnown = cfgServer.isEmpty() ? false : serverKnown;
    // retry the saved network, but not while a phone is on the setup page (retries make the AP hop channels)
    bool phoneOnSetup = portalOn && WiFi.softAPgetStationNum() > 0;
    if (!cfgSsid.isEmpty() && !phoneOnSetup && millis() - lastTry > 10000) { lastTry = millis(); WiFi.begin(cfgSsid.c_str(), cfgPass.c_str()); }
    if (millis() - lastOk > 60000) startPortal();     // lost for a minute: let the user fix it from a phone
  }
  if (digitalRead(0) == LOW) {                        // BOOT held for 5 s: forget Wi-Fi and server
    if (!bootDown) bootDown = millis();
    if (millis() - bootDown > 5000) {
      Preferences prefs; prefs.begin("s3hifi", false); prefs.clear(); prefs.end();
      Serial.println("settings erased");
      delay(200);
      ESP.restart();
    }
  } else bootDown = 0;
  if (millis() - t > 2000) {
    t = millis();
    Serial.printf("epoch %u %c vol %d | buf %.1f s @ %u Hz | played %llu | RSSI %d | server %s\n", streamEpoch, playState, volumePct,
                  outRate ? (double)(wr - rd) / ((double)outRate * (outBits / 8 * 2)) : 0.0, outRate, (unsigned long long)played, WiFi.RSSI(), serverKnown ? serverIp : "-");
  }
  delay(portalOn ? 2 : 20);
}

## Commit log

2026-10-02 Initial commit: hardware, case, streaming server and player firmware
    [lid.stl, platform.stl, terminal_board_bottom_marker.stl]
2026-10-04 Firmware 0.6: settings page at the player's address in the home network, 2 s prebuffer after a skip
    [player_fw.ino]
2026-10-04 Covers: download over http with fallbacks (Apple's https stalls or answers 403), find songs with several artists
2026-10-04 README: current status; no display on purpose, next is listening over mobile internet
2026-10-06 Case: keep only the STL files
2026-10-19 Player 0.7: USB DAC mode (UAC2, up to 24/96), Arduino core 3.3.8, firmware update over Wi-Fi
2026-10-22 0.8: English interface — remote, player setup page and flash.bat follow the browser / Windows language
    Russian browsers and Windows get Russian, everyone else English. The remote also translates the texts that come from the server (format line, errors); ?lang=en / ?lang=ru switches the remote by hand and is remembered.
2026-10-22 README: drop the language note, it switches by itself
2026-10-24 0.9: firmware update from the player's settings page, ffmpeg offered by both installers, review fixes
    - player: update over Wi-Fi from the settings page (progress, image check, optional password);
    buffer counters shared between the cores are read and written whole (rare click on long 24/96)
    - installers: install.sh asks to install ffmpeg and checks SHA256SUMS; the Windows installer
    follows the Windows language, offers ffmpeg with an explanation, license fixed to MIT
    - server: a radio station that stalls is dropped after 15 s; resampling works without SoX;
    tray menu in English on a non-Russian Windows
    - docs: ffmpeg for files above 96 kHz, DAC board with its own oscillator, short I2S wi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
2026-10-31 README: known issue — hiss in headphones from the DC-DC supply; 7805 supply schematic
2026-11-02 Terminal board v2: wire pads on the sides, away from the ESP32 antenna
    Wiring diagram follows the new board (antenna and USB drawn at the right ends).
    Drop the hiss note and the 7805 supply schematic.
2026-11-02 0.9.1: Wi-Fi transmit power on the player's setup page
